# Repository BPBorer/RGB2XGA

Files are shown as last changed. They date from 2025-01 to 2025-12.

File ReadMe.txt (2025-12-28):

RGB (256x192) input to SVGA (800x600) output
added the PCB files to the folder PCB/RGB2XGA

This project was built with "Raspberry Pi Pico SDK 1.5.1" and "Pico Visual Studio Code".

Details of RGB2XGA Project:

RGB inputs 

Pin 16, GP12 - Red Mid
Pin 17, GP13 - Red Hi
Pin 19, GP14 - Red Lo
Pin 20, GP15 - Green Mid
Pin 21, GP16 - Green Hi
Pin 22, GP17 - Green Lo
Pin 24, GP18 - Blue Mid
Pin 25, GP19 - Blue Hi

Pin 26, GP20 - H Sync
Pin 27, GP21 - V Sync 

SVGA (XGA) outputs

Pin 14, GP10 - H Sync
Pin 15, GP11 - V Sync

Pin 4, GP2 - Red Mid
Pin 5, GP3 - Red Hi
Pin 6, GP4 - Red Lo
Pin 7, GP5 - Green Mid
Pin 9, GP6 - Green Hi
Pin 10, GP7 - Green Lo
Pin 11, GP8 - Blue Mid
Pin 12, GP9 - Blue Hi

        GP25 - LED

Available

Pin 1, GP0 - UART0 Tx, Future option
Pin 2, GP1 - UART0 Rx, Future option

Pin 29, GP22 - unused
Pin 31, GP26 - unused
Pin 32, GP27 - unused 
Pin 34, GP28 - unused

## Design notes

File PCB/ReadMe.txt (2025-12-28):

The PCB files were created with DesignSpark PCB 11.0.
The working PCB were created from the gerbers in ZIP
folder at PCB/RGB2VGA/Manu/Manu.zip.

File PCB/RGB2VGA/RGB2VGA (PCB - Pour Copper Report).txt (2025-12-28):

Pour Copper Report
------------------

Report Written:     Monday, October 21, 2024
Design Path:        C:\CoCo\PCB\RGB2VGA\RGB2VGA.pcb
Design Title:       
Created:            2024-10-08 12:50:27 PM
Last Saved:         2024-10-21 12:46:27 AM
Editing Time:       2493 min
Units:              thou (precision 0)

End Of Report.

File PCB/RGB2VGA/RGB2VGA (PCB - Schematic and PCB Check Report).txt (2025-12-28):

Schematic and PCB Check Report
------------------------------

Report Written:     Friday, December 05, 2025
Design Path:        C:\CoCo\PCB\RGB2VGA\RGB2VGA.pcb
Design Title:       
Created:            2024-10-08 11:50:27 AM
Last Saved:         2025-12-05 7:49:56 PM
Editing Time:       4112 min
Units:              thou (precision 0)

Checking integrity of Schematic "C:\CoCo\PCB\RGB2VGA\RGB2VGA.sch" with PCB "C:\CoCo\PCB\RGB2VGA\RGB2VGA.pcb"
============================================================================================================

The PCB and Schematic designs do not match.
To bring them into line, you will need to make the following changes to the PCB design:

Change component reference "U7" to use package "PICO H" instead of package "DIL40".

End Of Report.

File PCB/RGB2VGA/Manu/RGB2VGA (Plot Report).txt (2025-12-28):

Plot Report
-----------

Report Written:     Friday, December 05, 2025
Design Path:        C:\CoCo\PCB\RGB2VGA\RGB2VGA.pcb
Design Title:       
Created:            2024-10-08 11:50:27 AM
Last Saved:         2025-12-05 7:49:56 PM
Editing Time:       4114 min
Units:              thou (precision 0)

Device Settings
===============

Gerber Settings
===============

    Leading zero suppression.
    G01 assumed throughout.
    Line termination <*> <CR> <LF>.
    3.5 format absolute inches.

    Format commands defined in Gerber file.
    Aperture table defined in Gerber file.
    Hardware arcs allowed.

Drill Settings
==============

    Excellon Format 2
    Format 3.5 absolute in inches.
    Zero suppression Leading

Plots Output
============

    Plot Job: "C:\CoCo\PCB\RGB2VGA\RGB2VGA.mop"

Gerber Output
=============

C:\CoCo\PCB\RGB2VGA\RGB2VGA - Top Copper.gbr

    Layers:
    ------------------
    Top Copper
    Board Outlines

    D-Code Shape  (thou)
    ----------------------------------------------
    D10    Round 12.00
    D11    Round 10.00
    D12    Round 20.00
    D14    Round 60.00
    D16    Rectangle 52.00 X 58.00  Rotation 90
    D74    Rectangle 52.00 X 58.00
    D91    Round 145.00
    D92    Rectangle 39.00 X 50.00
    D93    Rectangle 16.00 X 20.00  Rotation 90
    D94    Round 50.00
    D95    Round 200.00
    D96    Rectangle 25.00 X 80.00  Rotation 90
    D97    Oval 60.00 X 80.00  Rotation 90
    D98    Rectangle 13.00 X 18.00  Rotation 90

Gerber Output
=============

C:\CoCo\PCB\RGB2VGA\RGB2VGA - Top Solder Mask.gbr

    Layers:
    -------------------
    Top Solder Mask
    Board Outlines

    D-Code Shape  (thou)
    ----------------------------------------------
    D10    Round 12.00
    D19    Round 26.00
    D71    Round 66.00
    D21    Rectangle 58.00 X 64.00  Rotation 90
    D23    Round 5.00
    D82    Rectangle 58.00 X 64.00
    D99    Round 151.00
    D100   Rectangle 45.00 X 56.00
    D101   Rectangle 22.00 X 26.00  Rotation 90
    D102   Round 56.00
    D103   Round 206.00
    D104   Rectangle 31.00 X 86.00  Rotation 90
    D105   Oval 66.00 X 86.00  Rotation 90
    D106   Rectangle 19.00 X 24.00  Rotation 90

Gerber Output
=============

C:\CoCo\PCB\RGB2VGA\RGB2VGA - Top Paste Mask.gbr

    Layers:
    ------------------
    Top Paste Mask
    Board Outlines

    D-Code Shape  (thou)
    ----------------------------------------------
    D10    Round 12.00
    D25    Rectangle 46.00 X 52.00  Rotation 90
    D90    Rectangle 46.00 X 52.00
    D107   Rectangle 33.00 X 44.00
    D108   Rectangle 10.00 X 14.00  Rotation 90
    D109   Rectangle 19.00 X 74.00  Rotation 90
    D110   Rectangle 7.00 X 12.00  Rotation 90

Gerber Output
=============

C:\CoCo\PCB\RGB2VGA\RGB2VGA - Top Silkscreen.gbr

    Layers:
    ------------------
    Top Silkscreen
    Board Outlines

    D-Code Shape  (thou)
    -----------------------
    D10    Round 12.00
    D23    Round 5.00

Gerber Output
=============

C:\CoCo\PCB\RGB2VGA\RGB2VGA - GND Plane (Power Plane).gbr

    Layers:
    ----------------------------------------------------------------------------------------
    GND Plane       - Plane Isolation Gap 10.00 Thermal Connect Width 10.00 with 4 Spokes
    Board Outlines

    D-Code Shape  (thou)
    -------------------------------------------------------------
    D111   Round 20.00  Thermal Relief Pad
    D112   Round 32.00
    D113   Round 72.00
    D114   Round 60.00  Thermal Relief Pad
    D115   Round 145.00  Thermal Relief Pad
    D116   Round 50.00  Thermal Relief Pad
    D117   Round 62.00
    D118   Round 212.00
    D119   Oval 72.00 X 92.00  Rotation 90
    D120   Oval 60.00 X 80.00  Thermal Relief Pad  Rotation 90
    D121   Round 24.00

Gerber Output
=============

C:\CoCo\PCB\RGB2VGA\RGB2VGA - 3.3V Plane (Power Plane).gbr

    Layers:
    ----------------------------------------------------------------------------------------
    3.3V Plane      - Plane Isolation Gap 10.00 Thermal Connect Width 10.00 with 4 Spokes
    Board Outlines

    D-Code Shape  (thou)
    -------------------------------------------------------------
    D111   Round 20.00  Thermal Relief Pad
    D112   Round 32.00
    D113   Round 72.00
    D117   Round 62.00
    D118   Round 212.00
    D119   Oval 72.00 X 92.00  Rotation 90
    D120   Oval 60.00 X 80.00  Thermal Relief Pad  Rotation 90
    D121   Round 24.00
    D122   Round 62.00
    D123   Round 157.00

Gerber Output
=============

C:\CoCo\PCB\RGB2VGA\RGB2VGA - Bottom Copper.gbr

    Layers:
    ------------------
    Bottom Copper
    Board Outlines

    D-Code Shape  (thou)
    -----------------------------------------
    D10    Round 12.00
    D11    Round 10.00
    D12    Round 20.00
    D14    Round 60.00
    D91    Round 145.00
    D94    Round 50.00
    D95    Round 200.00
    D97    Oval 60.00 X 80.00  Rotation 90

Gerber Output
=============

C:\CoCo\PCB\RGB2VGA\RGB2VGA - Bottom Copper (Resist).gbr

    Layers:
    ------------------
    Bottom Copper
    Board Outlines

    D-Code Shape  (thou)
    -----------------------------------------
    D10    Round 12.00
    D124   Round 60.04
    D125   Round 145.04
    D126   Round 50.04
    D127   Round 200.04
    D128   Oval 60.04 X 80.04  Rotation 90

Gerber Output
=============

C:\CoCo\PCB\RGB2VGA\RGB2VGA - Gerber Drill Data - [Through Hole].gbr

    Layers:
    ------------------
    [Through Hole]

    D-Code Shape  (thou)
    -----------------------
    D27    Round 10.00
    D29    Round 38.00
    D129   Round 125.00
    D130   Round 32.00
    D131   Round 100.00
    D132   Round 40.00

NC Drill Output
===============

C:\CoCo\PCB\RGB2VGA\RGB2VGA - NC Drill Data - [Through Hole].drl

    Output:
    ---------------------------
    Plated Round Drill Holes
    Plated Slots

    Tool  Size           Count   ID
    --------------------------------------
    T001  0.01000 inches 94    H
    T002  0.03200 inches 10    A
    T003  0.03800 inches 15    D
    T004  0.04000 inches 40    M
    T005  0.10000 inches 2     C
    T006  0.12500 inches 2     L
    --------------------------------------
    Total                163
    --------------------------------------

C:\CoCo\PCB\RGB2VGA\RGB2VGA - NC Drill Data - [Through Hole] (Unplated).drl

    Output:
    -----------------------------
    Unplated Round Drill Holes
    Unplated Slots

    Tool  Size Count   ID
    ----------------------------
    ----------------------------
    Total      0
    ----------------------------

Gerber Output
=============

C:\CoCo\PCB\RGB2VGA\RGB2VGA - Drill Ident Drawing - [Through Hole].gbr

    Layers:
    ------------------
    [Through Hole]
    Board Outlines

Drill Ident Drawing
===================

    Drill Plated Size Shape ID
    -----------------------------------
    32    Y      100  Round A
    100   Y      100  Round C
    38    Y      100  Round D
    10    Y      100  Round H
    125   Y      100  Round L
    40    Y      100  Round M

    D-Code Shape  (thou)
    -----------------------
    D10    Round 12.00
    D23    Round 5.00
    D73    Round 100.00

End Of Report.

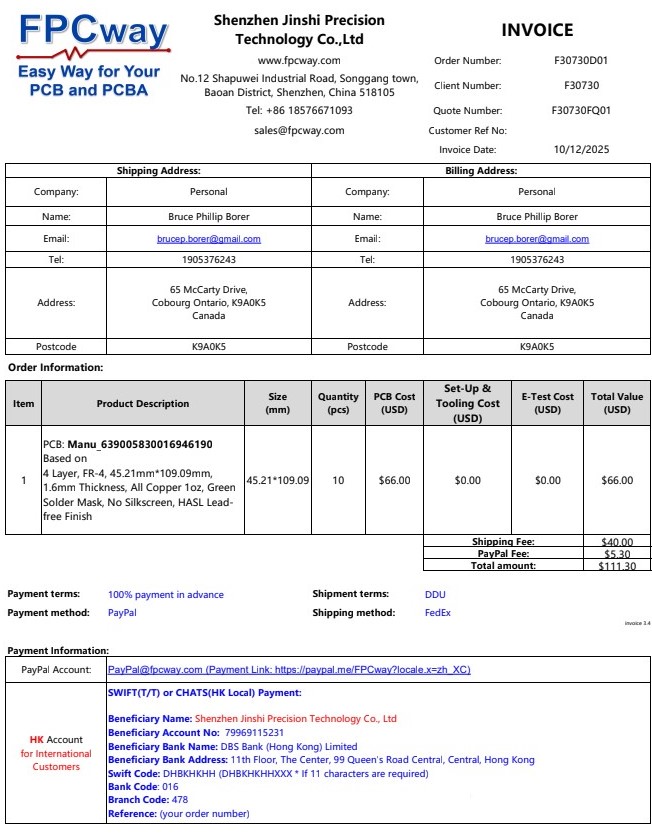
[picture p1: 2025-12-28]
PCB/RGB2VGA/Manu/invoice.jpg

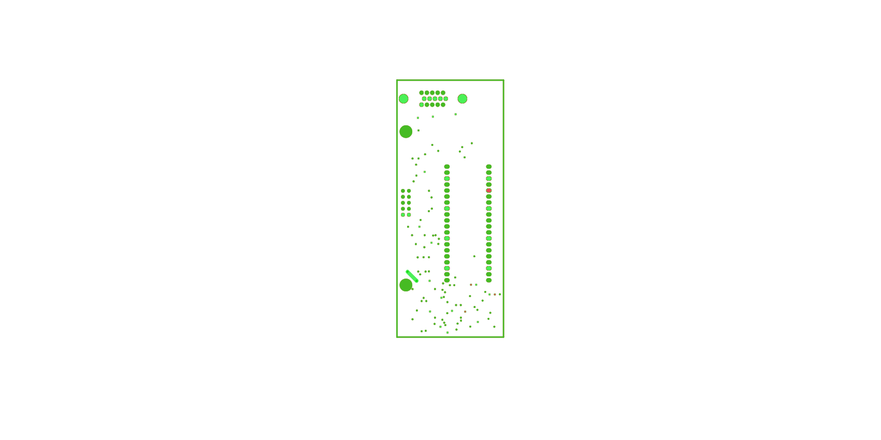
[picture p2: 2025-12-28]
PCB/RGB2VGA/Manu/3v3.png

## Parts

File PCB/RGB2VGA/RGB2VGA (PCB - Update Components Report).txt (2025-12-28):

Update Components Report
------------------------

Report Written:     Saturday, November 29, 2025
Design Path:        C:\CoCo\PCB\RGB2VGA\RGB2VGA.pcb
Design Title:       
Created:            2024-10-08 11:50:27 AM
Last Saved:         2025-11-29 3:05:45 PM
Editing Time:       2733 min
Units:              thou (precision 0)

Library Files:
==============

C:\Users\Public\Documents\DesignSpark PCB 11.0\Library\DownloadedLibrary\SnapEDA Downloads.cml
C:\Users\Public\Documents\DesignSpark PCB 11.0\Library\User\User.cml
C:\Users\Public\Documents\DesignSpark PCB 11.0\Library\Default\DesignSpark.cml
C:\Users\Public\Documents\DesignSpark PCB 11.0\Library\Default\ltspice.cml
C:\Users\Public\Documents\DesignSpark PCB 11.0\Library\Default\XSpice.cml

Selected items to be updated:
=============================

Components:
===========

    (None) 

Symbols:
========

    (None) 

Additional items to be updated:
===============================

Components:
===========

    (None) 

Symbols:
========

    (None) 

Selected items not to be updated  (Same version as library)
===========================================================

Components:
===========

CAP0805 (SMD0805)
CONN DIL 10 (CONN DIL 10)
DSub15Pin (DSUB15PIN)
MHsm (MHsm)
MIC94053 (SO706)
NAND2X4 (SOIC14)
NOR2X4 (SOIC14)
PICO H (DIL40)
SMD0805 (USER)
Zener (SOD523)

Symbols:
========

CONN DIL 10 C:\Users\Public\Documents\DesignSpark PCB 11.0\Library\Default\DesignSpark.psl
DSub15Pin   C:\Users\Public\Documents\DesignSpark PCB 11.0\Library\Default\DesignSpark.psl
MHsm        C:\Users\Public\Documents\DesignSpark PCB 11.0\Library\User\User.psl
PICO_H      C:\Users\Public\Documents\DesignSpark PCB 11.0\Library\Default\DesignSpark.psl
SMD0805     C:\Users\Public\Documents\DesignSpark PCB 11.0\Library\User\User.psl
SO14        C:\Users\Public\Documents\DesignSpark PCB 11.0\Library\Default\DesignSpark.psl
SO706       C:\Users\Public\Documents\DesignSpark PCB 11.0\Library\User\User.psl
SOD523      C:\Users\Public\Documents\DesignSpark PCB 11.0\Library\User\User.psl

Update Components Summary
=========================

Updating all components.
Update component values
Update component value positions
(Do not remove pad style exceptions on updated components)
	Selected for update:			  10  Components
						   8  Symbols
	Selected items to be updated:		   0  Components
						   0  Symbols
	Additional items to be updated:		   0  Components
						   0  Symbols
	Selected items NOT to be updated:	  10  Components
	  (Same version as library)		   8  Symbols

End Of Report.

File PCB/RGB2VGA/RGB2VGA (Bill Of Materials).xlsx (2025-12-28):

Report Written: | Tuesday, December 09, 2025
Design Path: | C:\CoCo\PCB\RGB2VGA\RGB2VGA.pcb
Design Title: | RGB@VGA
Created: | Bruce P. Borer
Last Saved: | 2025-12-05 20:43
Editing Time: | 4169 min
Units: | thou (precision 0)
Bill of Materials generated with DesignSpark PCB - www.DesignSpark.com/pcb
--------------------------------------------------------------------------
Ref Name | Qty | Component | Value | Package | MPN | Description
C1 | 1 | CAP0805 |  | SMD0805 | 10p | 0.1uF | NA
C2 | 1 | CAP0805 |  | SMD0805 | 10n | 0.1uF | NA
C3 | 1 | CAP0805 |  | SMD0805 | 10p | 0.1uF | NA
C4 | 1 | CAP0805 |  | SMD0805 |  | 0.1uF | NA
C5 | 1 | CAP0805 |  | SMD0805 |  | 0.1uF | NA
C6 | 1 | CAP0805 |  | SMD0805 | 0u1 | 0.1uF |  | 0.06
C7 | 1 | CAP0805 |  | SMD0805 | 0u1 | 0.1uF |  | 0.06
C8 | 1 | CAP0805 |  | SMD0805 | 0u1 | 0.1uF |  | 0.06
C12 | 1 | CAP0805 |  | SMD0805 | 0u1 | 0.1uF |  | 0.06
C11 | 1 | CAP0805 |  | SMD0805 | 0u1 | 0.1uF |  | 0.06
P3 | 1 | CONN DIL 10 |  | cable with male |  |  |  | 3.88
P3 | 1 | CONN DIL 10 |  | CONN DIL 10 |  | CONN DIL 10 |  | 0.22
P2 | 1 | DSub15Pin |  | DSUB15PIN |  | DSub15Pin |  | 1.62
U4 | 1 | MAX9108 |  | soic14 |  | quad comparitor |  | 3.72
U5 | 1 | MAX9108 |  | soic14 |  | quad comparitor |  | 3.72
U6 | 1 | MAX9108 |  | soic14 |  | quad comparitor |  | 3.72
MH1 | 1 | MHsm |  | MHsm |  | MHsm | NA
MH2 | 1 | MHsm |  | MHsm |  | MHsm | NA
Q1 | 1 | MIC94053 |  | SO706 |  | PFET |  | 0.78
U1 | 1 | NAND2X4 |  | SOIC14 |  | NAND |  | 0.36
U2 | 1 | NAND2X4 |  | SOIC14 |  | NAND |  | 0.36
U3 | 1 | NOR2X4 |  | SOIC14 |  | NOR |  | 0.16
U7 | 1 | PICO H |  | DIL40 |  | PICO H |  | 5.65
RN1 | 1 | R0804 |  | 804 |  | Quad Resistor |  | 0.04
RN2 | 1 | R0804 |  | 804 |  | Quad Resistor |  | 0.04
RN3 | 1 | R0804 |  | 804 |  | Quad Resistor |  | 0.04
RN4 | 1 | R0804 |  | 804 |  | Quad Resistor |  | 0.06
RN5 | 1 | R0804 |  | 804 |  | Quad Resistor |  | 0.06
RN6 | 1 | R0804 |  | 804 |  | Quad Resistor |  | 0.06
R1 | 1 | SMD0805 |  | USER | 430R | Resistor SMD |  | 0.02
R2 | 1 | SMD0805 |  | USER | 820R | Resistor SMD |  | 0.02
R4 | 1 | SMD0805 |  | USER | 430R | Resistor SMD |  | 0.02
R5 | 1 | SMD0805 |  | USER | 820R | Resistor SMD |  | 0.02
R6 | 1 | SMD0805 |  | USER | 1K6 | Resistor SMD |  | 0.02
R7 | 1 | SMD0805 |  | USER | 430R | Resistor SMD |  | 0.02
R8 | 1 | SMD0805 |  | USER | 820R | Resistor SMD |  | 0.02
R9 | 1 | SMD0805 |  | USER | 1K6 | Resistor SMD |  | 0.09
R10 | 1 | SMD0805 |  | USER | 3K17 | Resistor SMD |  | 0.11
R11 | 1 | SMD0805 |  | USER | 375R | Resistor SMD |  | 0.11
R12 | 1 | SMD0805 |  | USER | 375R | Resistor SMD |  | 0.02
R13 | 1 | SMD0805 |  | USER | 178R | Resistor SMD |  | 0.11
R14 | 1 | SMD0805 |  | USER | 897R | Resistor SMD |  | 0.02
R15 | 1 | SMD0805 |  | USER | 75R | Resistor SMD |  | 0.02
R16 | 1 | SMD0805 |  | USER | 75R | Resistor SMD |  | 0.02
R17 | 1 | SMD0805 |  | USER | 75R | Resistor SMD |  | 0.02
R18 | 1 | SMD0805 |  | USER | 2K0 | Resistor SMD |  | 0.03
R19 | 1 | SMD0805 |  | USER | 2K0 | Resistor SMD |  | 0.03
R20 | 1 | SMD0805 |  | USER | 3K0 | Resistor SMD |  | 0.02
R21 | 1 | SMD0805 |  | USER | 3K0 | Resistor SMD |  | 0.02
R3 | 1 | SMD0805 |  | USER | 1K6 | Resistor SMD |  | 0.02
ZD1 | 1 | Zener |  | SOD523 |  | Zener 2.5 |  | 0.13
ZD2 | 1 | Zener |  | SOD523 |  | Zener 2.5 |  | 0.13
ZD3 | 1 | Zener |  | SOD523 |  | Zener 2.5 |  | 0.13
ZD4 | 1 | Zener |  | SOD523 |  | Zener 2.5 |  | 0.13
ZD5 | 1 | Zener |  | SOD523 |  | Zener 2.5 |  | 0.13
U7 | 1 |  |  | 42 pin |  |  |  | 1.19
PCB | 1 |  |  |  |  |  |  | 30
 |  |  |  |  |  |  |  | 57.41

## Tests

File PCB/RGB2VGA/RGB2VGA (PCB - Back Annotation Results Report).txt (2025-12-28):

Back Annotation Results Report
------------------------------

Report Written:     Thursday, December 04, 2025
Design Path:        C:\CoCo\PCB\RGB2VGA\RGB2VGA.pcb
Design Title:       
Created:            2024-10-08 11:50:27 AM
Last Saved:         2025-12-04 9:58:09 PM
Editing Time:       3867 min
Units:              thou (precision 0)

Back Annotate renames from PCB "C:\CoCo\PCB\RGB2VGA\RGB2VGA.pcb" to Schematic "C:\CoCo\PCB\RGB2VGA\RGB2VGA.sch".

End Of Report.

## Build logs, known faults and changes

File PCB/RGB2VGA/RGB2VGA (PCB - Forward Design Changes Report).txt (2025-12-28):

Forward Design Changes Report
-----------------------------

Report Written:     Friday, December 05, 2025
Design Path:        C:\CoCo\PCB\RGB2VGA\RGB2VGA.pcb
Design Title:       
Created:            2024-10-08 11:50:27 AM
Last Saved:         2025-12-05 7:28:41 PM
Editing Time:       4112 min
Units:              thou (precision 0)

Ignored different package for component reference "U7", schematic uses package "PICO H", and PCB uses package "DIL40".

Net N0326 renamed to N0536

End Of Report.

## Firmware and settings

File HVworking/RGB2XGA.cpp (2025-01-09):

#include <stdio.h>
#include "pico/stdlib.h"
#include "hardware/dma.h"
#include "hardware/pio.h"
#include "hardware/pll.h"
#include "hardware/clocks.h"
#include "hardware/structs/pll.h"
#include "hardware/structs/clocks.h"

#include "XGAvSync.pio.h"
#include "RGB_PIn.pio.h"
#include "XGAhSync.pio.h"
#include "XGAPixs.pio.h"

// Data will be copied from src to dst
const char src[] = "Hello, world! (from DMA)";
char dst[count_of(src)];

 #ifndef LED_DELAY_MS
 #define LED_DELAY_MS 250
 #endif


int main()
{   // Sys Clock set for 160 MHz.
    set_sys_clock_pll(1440000000, 3, 3);

    stdio_init_all();

// DMA channels - 0 sends/receives color data, 1 reconfigures and restarts 0
    int      rgb_chan_0 = 0;
    int      rgb_chan_1 = 1;
    PIO      rgb_pio    = pio0;
    uint     rgb_sm     = 0;
    uint32_t rgb_Rx_Cnt = (101 * 192);
    int      xga_chan_0 = 2;
    int      xga_chan_1 = 3;
    PIO      xga_pio    = pio1;
    uint     smvSync    = 0;
    uint     smhSync    = 1;
    uint     smXGAPixs  = 2;
    uint32_t xga_Tx_Cnt = (101 * 192);     // 101*4  = 404 bytes
    uint32_t *xga_lines[192*2];   
    uint32_t vga_data_array[101 * 192];
    uint     x;

   //pico_led_init();
   gpio_init(PICO_DEFAULT_LED_PIN);
   gpio_set_dir(PICO_DEFAULT_LED_PIN, GPIO_OUT);

   //stdio_init_all();

    for (x = 0; x < xga_Tx_Cnt; x++) {
        vga_data_array[x] = 0xcca97613;
    }

    xga_lines[0] = &vga_data_array[0];
    xga_lines[192*2-1] = &vga_data_array[0];    
    for (x = 1; x < (192-2); x+=2) {
        xga_lines[x] = &vga_data_array[(x * 101)];
        xga_lines[x+1] = &vga_data_array[x * 101];
    }

    sleep_ms(LED_DELAY_MS*9);
    
    uint offseth = pio_add_program(xga_pio, &XGAhSync_program);
    printf("XGAhSync pin %d with offset %d\n", 10, offseth);
    XGAhSync_program_init(xga_pio, smhSync, offseth, 10);
    //pio_sm_set_enabled(xga_pio, smhSync, true);
    xga_pio->txf[smhSync] = (440);

    uint offsetv = pio_add_program(xga_pio, &XGAvSync_program);
    printf("XGAvSync pin %d with offset %d\n", 11, offsetv);
    XGAvSync_program_init(xga_pio, smvSync, offsetv, 11);
    pio_sm_set_enabled(xga_pio, smvSync, true);
    xga_pio->txf[smvSync] = (601);

    uint offsetp = pio_add_program(xga_pio, &XGAPixs_program);
    printf("XGAPixs pin %d with offset %d\n", 2, offsetp);
    XGAPixs_program_init(xga_pio, smXGAPixs, offsetp, 2);
    pio_sm_set_enabled(xga_pio, smXGAPixs, true);
    xga_pio->txf[smXGAPixs] = (404);
    // xga_pio->txf[smXGAPixs] = (0xcca97613);
    // xga_pio->txf[smXGAPixs] = (0xcca97613);
    // xga_pio->txf[smXGAPixs] = (0xcca97613);

    uint offsetr = pio_add_program(rgb_pio, &RGB_PIn_program);
    printf("RGB_PIn %d with offset %d\n", 12, offsetr);
    RGB_PIn_program_init(rgb_pio, rgb_sm, offsetr, 12);
    pio_sm_set_enabled(rgb_pio, rgb_sm, true);
    xga_pio->txf[rgb_sm] = (404);

    // 32 bit transfers. Both read and write address increment after each
    // transfer (each pointing to a location in src or dst respectively).
    // DREQ is selected, so the DMA transfers are controlled.
    
    // Channel Three (reconfigures the first XGA channel)
    dma_channel_config c1 = dma_channel_get_default_config(xga_chan_1);   // default configs
    channel_config_set_transfer_data_size(&c1, DMA_SIZE_32);              // 32-bit txfers
    channel_config_set_read_increment(&c1, false);                        // no read incrementing
    channel_config_set_write_increment(&c1, false);                       // no write incrementing
    channel_config_set_chain_to(&c1, xga_chan_0);                         // chain to other channel

    dma_channel_configure(
        xga_chan_1,                         // Channel to be configured
        &c1,                                // The configuration we just created
        &vga_data_array,                    // Write address (POINTER TO AN ADDRESS)
        &dma_hw->ch[xga_chan_0].read_addr,  // Read address (channel 0 read address)
        1,                                  // Number of transfers, in this case each is 4 byte
        true                                // start immediately.
    );

    // Channel One (reconfigures the first RGB channel)
    dma_channel_config c3 = dma_channel_get_default_config(rgb_chan_1);   // default configs
    channel_config_set_transfer_data_size(&c3, DMA_SIZE_32);              // 32-bit txfers
    channel_config_set_read_increment(&c3, false);                        // no read incrementing
    channel_config_set_write_increment(&c3, false);                       // no write incrementing
    channel_config_set_chain_to(&c3, rgb_chan_0);                         // chain to other channel

    dma_channel_configure(
        rgb_chan_1,                         // Channel to be configured
        &c3,                                // The configuration we just created
        &dma_hw->ch[rgb_chan_0].write_addr, // Write address (channel 0 read address)
        &vga_data_array,                    // Read address (POINTER TO AN ADDRESS)
        1,                                  // Number of transfers, in this case each is 4 byte
        true                                // start immediately.
    );
    // Channel Zero (gets color data from PIO RGB machine)
    dma_channel_config c2 = dma_channel_get_default_config(rgb_chan_0);  // default configs
    channel_config_set_transfer_data_size(&c2, DMA_SIZE_32);       // 32-bit txfers
    channel_config_set_read_increment(&c2, false);                 // no read incrementing
    channel_config_set_write_increment(&c2, true);                 // yes write incrementing
    channel_config_set_dreq(&c2, DREQ_PIO0_RX0) ;                  // DREQ_PIO0_RX0 pacing (FIFO)
    channel_config_set_chain_to(&c2, rgb_chan_1);                  // chain to other channel

    dma_channel_configure(
        rgb_chan_0,                 // Channel to be configured
        &c2,                        // The configuration we just created
        &vga_data_array,            // The initial write address (pixel color array)
        &rgb_pio->rxf[rgb_sm],      // read address (RGB PIO TX FIFO)
        rgb_Rx_Cnt,                 // Number of transfers; in this case each is 4 bytes.
        true                        // start immediately.
    );

    // Channel Two (Sends color data to PIO XGA machine)
    dma_channel_config c0 = dma_channel_get_default_config(xga_chan_0);  // default configs
    channel_config_set_transfer_data_size(&c0, DMA_SIZE_32);       // 32-bit txfers
    channel_config_set_read_increment(&c0, true);                  // yes read incrementing
    channel_config_set_write_increment(&c0, false);                // no write incrementing
    channel_config_set_dreq(&c0, DREQ_PIO1_TX2) ;                  // DREQ_PIO1_TX2 pacing (FIFO)
    channel_config_set_chain_to(&c0, xga_chan_1);                  // chain to other channel

    dma_channel_configure(
        xga_chan_0,                 // Channel to be configured
        &c0,                        // The configuration we just created
        &xga_pio->txf[smXGAPixs],   // The write address (RGB PIO TX FIFO)
        &vga_data_array,            // The initial read address (pixel color array)
        xga_Tx_Cnt,                 // Number of transfers; in this case each is 4 bytes.
        true                        // start immediately.
    );



    while (true) {
    printf("Hello, world!\n");
    // sleep_ms(1000);
    // pico_set_led(true);
    // if (pis_sm2_tx_fifo_not_full) xga_pio->txf[smXGAPixs] = (0xcca97613);
    // if (pis_sm2_tx_fifo_not_full) xga_pio->txf[smXGAPixs] = (0xcca97613);
    gpio_put(PICO_DEFAULT_LED_PIN, 1);
    sleep_ms(LED_DELAY_MS*2);
    // pico_set_led(false);
    // if (pis_sm2_tx_fifo_not_full) xga_pio->txf[smXGAPixs] = (0xcca97613);
    // if (pis_sm2_tx_fifo_not_full) xga_pio->txf[smXGAPixs] = (0xcca97613);
    gpio_put(PICO_DEFAULT_LED_PIN, 0);
    sleep_ms(LED_DELAY_MS*2);
    }
}

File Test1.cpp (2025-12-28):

#include <stdio.h>
#include "pico/stdlib.h"
#include "hardware/pio.h"
#include "hardware/pll.h"
#include "hardware/dma.h"
#include "hardware/clocks.h"
#include "hardware/structs/pll.h"
#include "hardware/structs/clocks.h"

// #include "blink.pio.h"
#include "XGAPixs.pio.h"
#include "XGAhSync.pio.h"
#include "XGAvSync.pio.h"
#include "RGBFP.pio.h"
#include "RGBline.pio.h"
#include "RGBPixs.pio.h"

#ifndef LED_DELAY_MS
#define LED_DELAY_MS 2
#endif

#define pixels   400
#define RGBlines 192
#define XGAlines 600
#define rgb_Rx_Cnt (pixels / 4) * 192 // 19200   //
#define xga_Tx_Cnt (pixels / 4) * 300 // 30000   //
#define Ins_PULL    0x80A0
#define Ins_MOV2ISR 0xA0C7
#define Ins_MOV2Y   0xA047

io_rw_32 *xga_lines[XGAlines]; // [RGBlines*2];
int xga_chan_0;
int xga_chan_1;
int n, x;
uint32_t *XGAaddr_pointer;
uint32_t vga_data_array[xga_Tx_Cnt + 100];

/* void DMA_IRQ_handler()
{
    extern io_rw_32 *xga_lines[];
    extern int xga_chan_0;
    extern long unsigned int *lineptr;
    extern int n, x;
//    extern uint32_t *XGAaddr_pointer;
    extern uint32_t vga_data_array[];

    XGAaddr_pointer = &vga_data_array[n * pixels / 4];

    irq_clear(PIO0_IRQ_0);
    gpio_put(PICO_DEFAULT_LED_PIN, 1);

    x++;
    if (x >= 2)
    {
        n++;
        x = 0;
    }
    if (n >= (XGAlines / 2) - 1)
        n = 0;
    gpio_put(PICO_DEFAULT_LED_PIN, 0);
}
*/
int main()
{   extern io_rw_32 *xga_lines[];
    extern int xga_chan_0;
    extern int n, x;
    extern uint32_t *XGAaddr_pointer;
    extern uint32_t vga_data_array[];


    PIO RGB_pio = pio1;
    PIO xga_pio = pio0;
    uint smXGAPixs = 1;
    uint smvSync   = 2;
    uint smhSync   = 3;

    uint smRGBFP   = 0;
    uint smRGBline = 1;
    uint smRGBPixs = 2;

    uint y;
    uint instrs[2] = {0xA047, 0x80A0};
    uint32_t *RGBaddr_pointer = &vga_data_array[0];

    uint32_t Data[8];
    uint32_t Col, DataPtr;
    char     MessPtr;
    int      i,j; 
    static char Message[29*6] = {
        0x84, 0x84, 0x84, 0xFC, 
        0x54, 0x38, 0x00, 0x78,  // D
        0x00, 0x24, 0x54, 0x54,  // e
        0x54, 0x54, 0x54, 0x24,  
        0x00, 0x00, 0x00, 0x48,  // s
        0x00, 0x00, 0x00, 0x5C,  // i
        0x25, 0x25, 0x25, 0x18, 
        0x10, 0x3C, 0x00, 0x1E,  // g
        0x00, 0x1C, 0x20, 0x20,  // n
        0X54, 0X54, 0X54, 0X38, 
        0x14, 0x08, 0X00, 0X24,  // e
        0x00, 0xFC, 0x14, 0x14,  // d
        0x00, 0x00, 0x00, 0x00, 
        0x14, 0xFC, 0x00, 0x00,  // space
        0x00, 0x08, 0x14, 0x14,  // b
        0x05, 0x05,0x05, 0x19,  
        0x00, 0x00, 0x00, 0x1E,  // y
        0x00, 0x00, 0x00, 0x00,  // space
        0xA4, 0xA4, 0xA4, 0xFC, 
        0x10, 0x3C, 0x00, 0x58,  // B
        0x00, 0x10, 0x20, 0x20,  // r
        0x04, 0x04, 0x04, 0x38, 
        0x24, 0x18, 0x00, 0x38,  // u
        0x00, 0x24, 0x24, 0x24,  // c
        0X54, 0X54, 0X54, 0X38, 
        0x00, 0x00, 0X00, 0X24,  // e
        0x00, 0x00, 0x00, 0x00,  // space
        0xA0, 0xA0, 0xA0, 0xFC, 
        0x00, 0x00, 0x00, 0x40,  // P
        0x00, 0x00, 0x0C, 0x0C,  // .
        0x00, 0x00, 0x00, 0x00, 
        0xA4, 0xFC, 0x00, 0x00,  // space
        0x00, 0x58, 0xA4, 0xA4,  // B
        0x24, 0x24, 0x24, 0x18, 
        0x10, 0x3C, 0x00, 0x18, // o
        0x00, 0x10, 0x20, 0x20,  // r
        0X54, 0X54, 0X54, 0X38, 
        0x10, 0x3C, 0X00, 0X24,  // e
        0x00, 0x10, 0x20, 0x20,  // r
        0x00, 0x00, 0x00, 0x00, 
        0x00, 0x00, 0x00, 0x00,  // space
        0x00, 0x00, 0x00, 0x00   // space
    };

// Sys Clock set for 160 MHz.
    set_sys_clock_pll(1440000000, 3, 3);

    stdio_init_all();
    gpio_init(PICO_DEFAULT_LED_PIN);
    gpio_set_dir(PICO_DEFAULT_LED_PIN, GPIO_OUT);

   for (x = 0; x < rgb_Rx_Cnt; x++)
    {
        vga_data_array[x] = 0x00010100 * x;
    }
    for (x = rgb_Rx_Cnt; x < xga_Tx_Cnt ; x++)
    {
        vga_data_array[x] = 0;
    }
    vga_data_array[0] = 0xFFFF0000;
    vga_data_array[4] = 0;
    vga_data_array[104] = 0;
    vga_data_array[204] = 0;
    vga_data_array[304] = 0;
    vga_data_array[404] = 0;
    vga_data_array[504] = 0;
    vga_data_array[604] = 0;
    vga_data_array[704] = 0;
    vga_data_array[10] = 0;
    vga_data_array[50] = 0;
    vga_data_array[99] = 0;
    vga_data_array[199] = 0;
    vga_data_array[299] = 0;
    vga_data_array[399] = 0;
    vga_data_array[499] = 0;
    vga_data_array[29900] = 0;
    vga_data_array[30000] = 0;

    vga_data_array[rgb_Rx_Cnt + 204] = 0xFFFFFFFF;

    XGAaddr_pointer = &vga_data_array[0];

    DataPtr = 24106;
    for (MessPtr = 0; MessPtr < 28*6; MessPtr = MessPtr+4){
        for (i=0; i<8; i++) {
            Data[i] = 0;
        }
         for (j=0; j < 4; j++) {
            Col = Message[MessPtr+j];
            for (i=0; i<8; i++) {
                Data[i] = Data[i] << 8;
                if (Col & (1<<i)) Data[i] = Data[i] + 0xFF;
            }
        }
        for (i = 0; i < 8; i++) {
            vga_data_array[DataPtr+(i * 100)] = Data[7-i];
        }
        DataPtr = DataPtr + 1;
   } 

    n = 0;
    x = 0;

    sleep_ms(LED_DELAY_MS * 1000);
 
    gpio_set_drive_strength(2, GPIO_DRIVE_STRENGTH_12MA);
    gpio_set_drive_strength(3, GPIO_DRIVE_STRENGTH_12MA);
    gpio_set_drive_strength(4, GPIO_DRIVE_STRENGTH_12MA);
    gpio_set_drive_strength(5, GPIO_DRIVE_STRENGTH_12MA);
    gpio_set_drive_strength(6, GPIO_DRIVE_STRENGTH_12MA);
    gpio_set_drive_strength(7, GPIO_DRIVE_STRENGTH_12MA);
    gpio_set_drive_strength(8, GPIO_DRIVE_STRENGTH_12MA);
    gpio_set_drive_strength(9, GPIO_DRIVE_STRENGTH_12MA);
    gpio_set_drive_strength(10, GPIO_DRIVE_STRENGTH_12MA);
    gpio_set_drive_strength(11, GPIO_DRIVE_STRENGTH_12MA);

    uint offseth = pio_add_program(xga_pio, &XGAhSync_program);
    XGAhSync_program_init(xga_pio, smhSync, offseth, 10);
    xga_pio->txf[smhSync] = (440);         //; Active+FP (400+40) =  440
    xga_pio->sm[smhSync].instr = Ins_PULL; // pull  block
    pio_sm_set_enabled(xga_pio, smhSync, true);

    uint offsetv = pio_add_program(xga_pio, &XGAvSync_program);
    XGAvSync_program_init(xga_pio, smvSync, offsetv, 11);
    xga_pio->txf[smvSync] = (XGAlines - 1);
    xga_pio->sm[smvSync].instr = Ins_PULL; // pull  block
    pio_sm_set_enabled(xga_pio, smvSync, true);

    uint offsetp = pio_add_program(xga_pio, &XGAPixs_program);
    XGAPixs_program_init(xga_pio, smXGAPixs, offsetp, 2);
    xga_pio->txf[smXGAPixs] = (pixels - 1);
    xga_pio->sm[smXGAPixs].instr = Ins_PULL;    // pull  block
    xga_pio->sm[smXGAPixs].instr = Ins_MOV2ISR; // mov   isr, osr
    pio_sm_set_enabled(xga_pio, smXGAPixs, true);

    uint offsetR = pio_add_program(RGB_pio, &RGBFP_program);
    RGBFP_program_init(RGB_pio, smRGBFP, offsetR, 26);
    RGB_pio->txf[smRGBFP] = 39;
    RGB_pio->sm[smRGBFP].instr = Ins_PULL; // pull  block
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
